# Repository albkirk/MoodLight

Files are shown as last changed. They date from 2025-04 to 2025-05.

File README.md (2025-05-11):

# MoodLight Project

This device aims to build a cozy, or inspirational, or emotive ambient surrounding you. For that, it uses a colorful 8x8 LED matrix to blast you with the mood.
It finds the right mood to transmit thanks to the information acquired by the sensors: temperature*, humidity*, light* and sound level*, detected BT* or WiFi* devices, weather forecast*, etc..
The set of colors, the visual pattern effect and brightness intensity are selected to create the perfect ambient.

(* planned integration)

## Supported Features

    1.  Single color or multi-color smooth transition,
    2.  "mood" profiles with customizable color pallete (Hot, Cool, Nature, Inspire,...),
    3.  Manual selection of "mood" profile,
    4.  Selects the right "mood" profile, based on ambient data reading,*
    5.  Auto-OFF Timer, configurable using Home Assistant, using the buttons* with the LED matrix as "Display",*
    6.  Light intensity adjust manually, or based on ambient light,*
    7.  Flashlight (Long press Mode Button),
    8.  Works everywhere, regardless of Wi-Fi newtork availability,
    9.  [Home Assistant](https://www.home-assistant.io) integration,
    10. [WLED](https://kno.wled.ge) compatible.
        (* Future integration)

## Used components

    - LilyGo T7 v1.3 ESP32 MCU,
    - WS2812b LED 5050 RGB 8x8 64 LED Matrix,
    - 18650 LiPo battery,
    - TP4056 battery charger module (embeded in the T7),
    - 1 Button (embeded in the T7),
    - AHT10 temperature and humidity sensor, *
    - Electret Microphone module, *
    - Light sensor resistor (LDR), * 
        (* Future integration)

## PinOut

    ESP32   |   WS2812b
    5v      |   V+
    GND     |   V-
    IO16    |   In 

## Technical Requirements

    - Define "Mood Profiles" with predifined name, color selection (may have diferent number of colors), effect pattern (Led to light-up, color to apply)

    - Use push buttons with single press, or n presses, or long press.

    - Use the matrix as output display, like timer definition, selected EFX, etc. Ex.: each led may represent 5 minutes of the ON timer, or flash green for "OK", or draw a red cross for "NOK" or "Cancel" message.

    - Battery powered to take it anywhere

    - Handy flash light (White color full brightness)

## Case
https://cad.onshape.com/documents/a11340a8b514efb50a936062/w/a1de64b26606eb292ac9daf7/e/f47711be4b7f09a631f87059

*STL Files*:
[ - Front -](Media/Mood-Front.stl)
[- Back -](Media/Mood-Back.stl)
[- Matrix -](Media/Mood-Matrix.stl)
[- Mode Button -](Media/Mood-Mode.stl)
[- PWR Switch -](Media/Mood-PWR.stl)

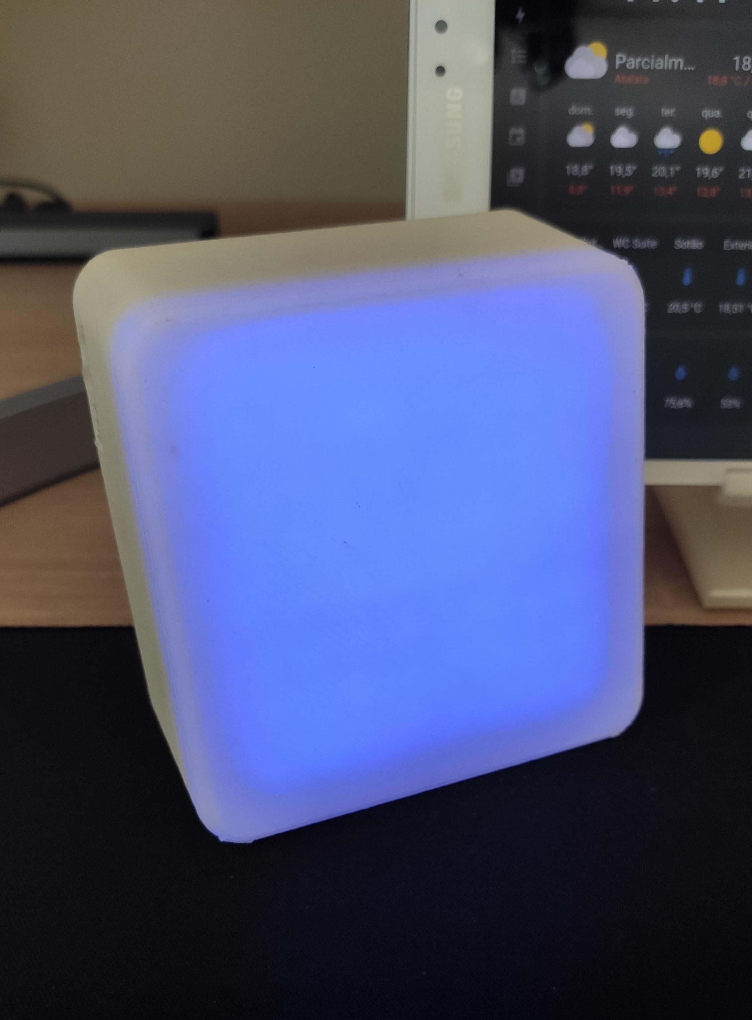
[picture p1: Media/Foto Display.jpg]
Foto Display

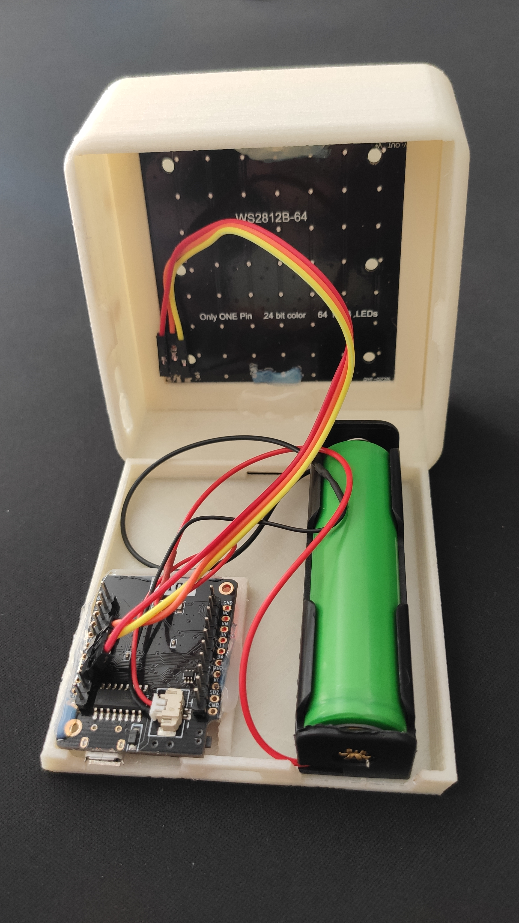
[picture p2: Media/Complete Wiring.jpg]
Complete Wiring


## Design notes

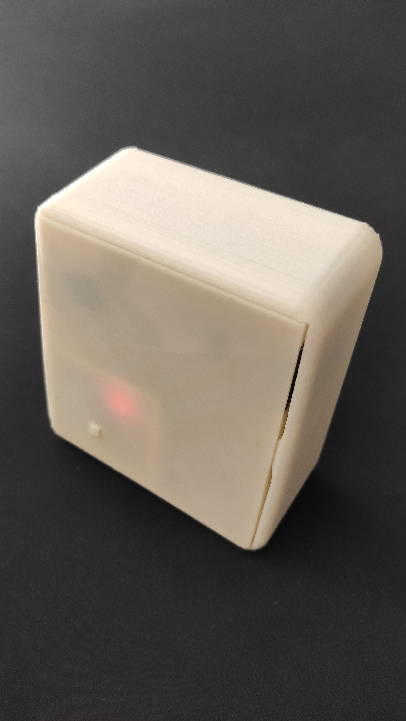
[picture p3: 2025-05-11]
Media/Real View Back.jpg

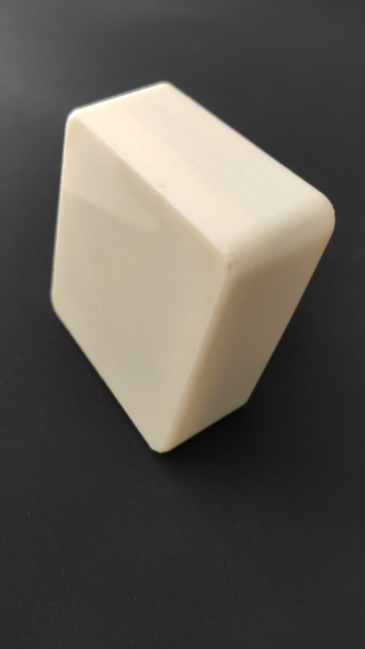
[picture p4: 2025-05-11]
Media/Real View.jpg

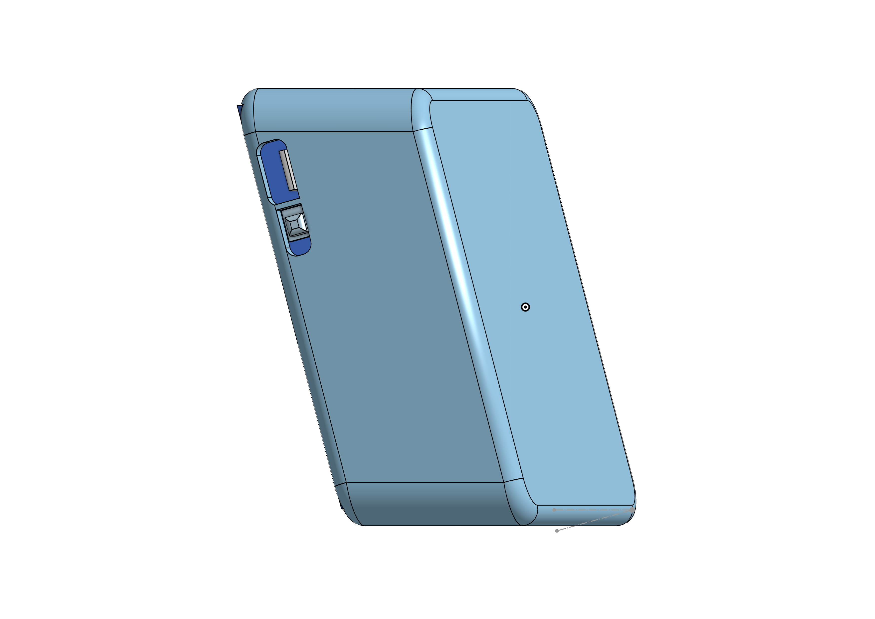
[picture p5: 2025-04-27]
Media/image.png

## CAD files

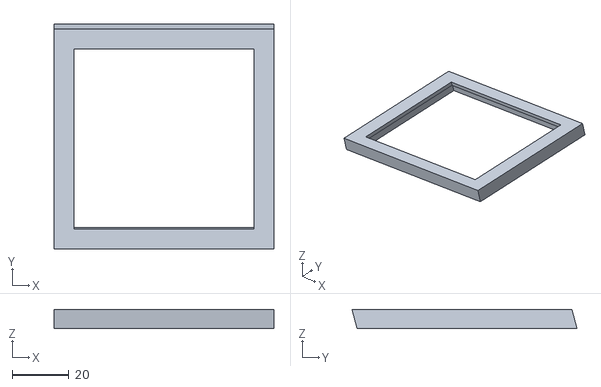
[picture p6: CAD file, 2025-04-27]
Media/Mood-Matrix.stl
77.6 x 79.4 x 6.76

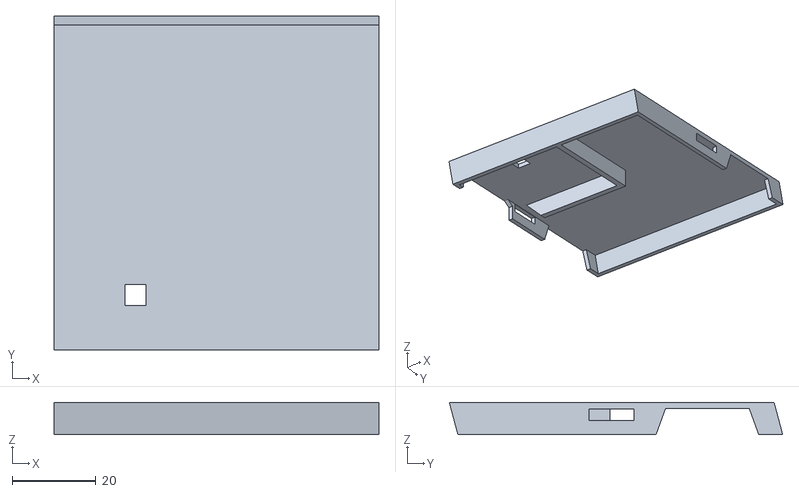
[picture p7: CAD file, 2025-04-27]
Media/Mood-Back.stl
77.6 x 79.6 x 7.73

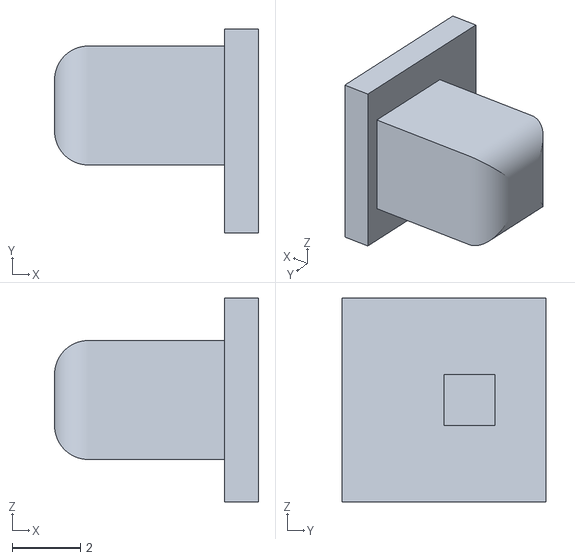
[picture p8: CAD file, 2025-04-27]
Media/Mood-PWR.stl
6.00 x 6.00 x 6.00

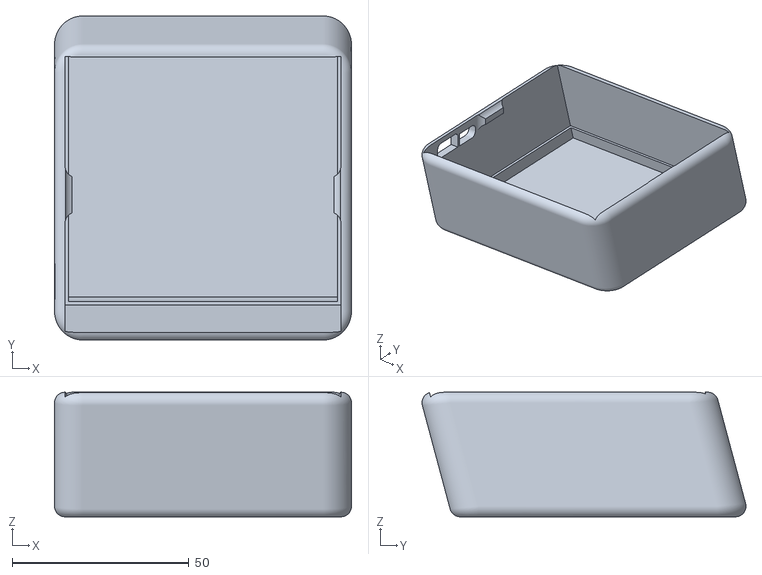
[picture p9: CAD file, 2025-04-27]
Media/Mood-Front.stl
84.0 x 91.6 x 35.3

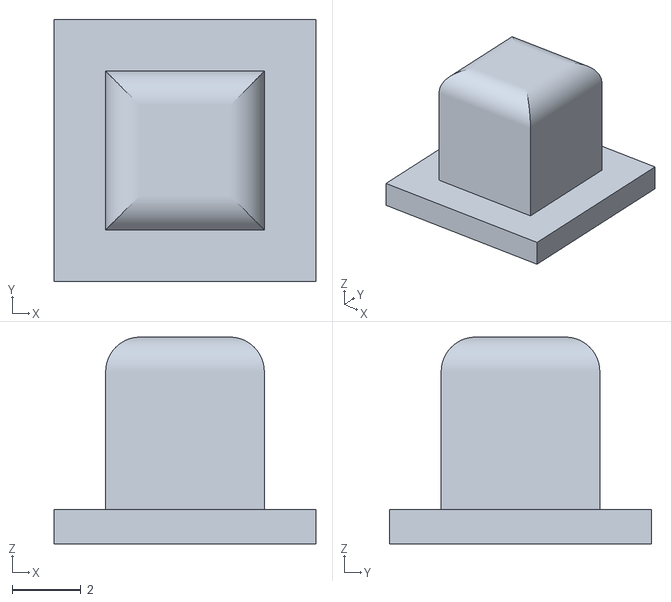
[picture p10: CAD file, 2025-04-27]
Media/Mood-Mode.stl
7.60 x 7.60 x 6.00

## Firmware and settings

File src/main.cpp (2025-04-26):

/*
 * * Main File to trigger all C code using "arduino" style.
 * * It contains all necessary function calls on setup and loop functions
 * * HOW TO USE THIS TEMPLATE:
 * * -- Keep this file as is. and use the lib/project/project.h 
 * *    Use the "// **** Normal code ..." zones to add you own definition, functions, setup and loop code
 * * -- Suggest to use "lib/project/" to add your own h files
 * * -- Adjust the PIN numbering  in lib/project/def_conf.h
 * * -- Adjust the "default.config" in lib/project/def_conf.h
 * * -- Add you own HASSIO discovery declaration on "lib/project/custohassio.h"
 * * -- Add you own MQTT actions on "lib/project/customactions.h"
 */

// Libraries to INCLUDE
#include <storage.h>

#ifdef ESP32
    #include <esp32hw.h>
#else
    #include <hw8266.h>
#endif

#include <mywifi.h>

//#ifdef ESP8266
//    #include <httpupd.h>
//#endif

#include <console.h>
#include <ntp.h>
#include <mqtt.h>
#include <peripherals.h>
#include <global.h>
#include <ota.h>
#include <hassio.h>
#ifndef ESP8285
    #include <web.h>
#endif
#include <project.h>
#include <actions.h>                        // Added later because functions from project are called here.


void setup() {
  // Starting with WiFi interface shutdown in order to save energy
    wifi_disconnect();

  // Start SERIAL console
      //Serial.begin(74880);                  // This odd baud speed will shows ESP8266 boot diagnostics too.
      Serial.begin(115200);                 // For faster communication use 115200
      //Serial.setTimeout(1000);
      //Serial.setDebugOutput(false);

      Serial.println("");
      Serial.println(" -- Hello World! -- ");
      Serial.println("My ID is " + ChipID + " and I'm running version " + SWVer);
      Serial.println("Reset reason: " + ESPResetReason());

  // Start Storage service and read stored configuration
      storage_setup();

  // Start Global features, such as: ESP_LED, Buzzer, internal ADC, ...
      global_setup();

  //  Project peripherals initialization, such as: GPIO config, Sensors, Actuators, ...  
      peripherals_setup();

  // Start WiFi service (Station or/and as Access Point)
      wifi_setup();

  // Check for HTTP Upgrade
//#ifdef ESP8266
//      http_upg();               // Note: this service kills all running UDP and TCP services
//#endif
  // Start TELNET console service
      telnet_setup();

 // Start MQTT service
      mqtt_setup();

  // Start OTA service
      ota_setup();

  // Start NTP service
      ntp_setup();

  // **** Project SETUP Sketch code here...
      project_setup();

#ifndef ESP8285
  // Start ESP Web Service
      if (config.WEB) web_setup();
#endif

  // with all setup tasks done it's time to prompt!
      console_prompt();

  // Last bit of code before leave setup
      ONTime_Offset = millis() + 200UL;     //  200ms after finishing the SETUP function it starts the "ONTime" countdown.
                                            //  it should be good enough to receive the MQTT "ExtendONTime" msg
} // end of setup()


void loop() {
  // allow background process to run.
      yield();

  // Global handling, namely the button to return to default configuration
      //global_loop();

  // WiFi handling
      wifi_loop();

  // Serial handling
      serial_loop();

  // TELNET handling
      if (config.TELNET) telnet_loop();

  // MQTT handling
      mqtt_loop();

  // OTA request handling
      if (config.OTA) ota_loop();

  // NTP handling
      ntp_loop();

#ifndef ESP8285
  // ESP Web Server requests handling
      if (config.WEB) web_loop();
#endif

  // **** Project LOOP Sketch code here ...
      project_loop();

  // Global loops handling
    global_loop();
    
}  // end of loop()

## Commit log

2025-04-26 V01.01 One button control Basic, but stable! : )
2025-04-27 V01.02 EFX Color Tunning
    [Mood-Back.stl, Mood-Front.stl, Mood-Matrix.stl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]
2025-05-11 v01.03 - Adding media content to enrich the project description
    [Mood-Back.stl, Mood-Front.stl, Mood-Matrix.stl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]
2025-05-11 v01.04 - Disable the (unnecessary) builtin LED
